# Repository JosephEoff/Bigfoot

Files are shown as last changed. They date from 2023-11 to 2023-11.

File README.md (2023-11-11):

# Bigfoot
Bigfoot is a sewing machine motor speed control made to truly control the speed rather than merely regulating the power.

|Bigfoot and an Adler class 8 sewing machine|
|------------------------------------------|
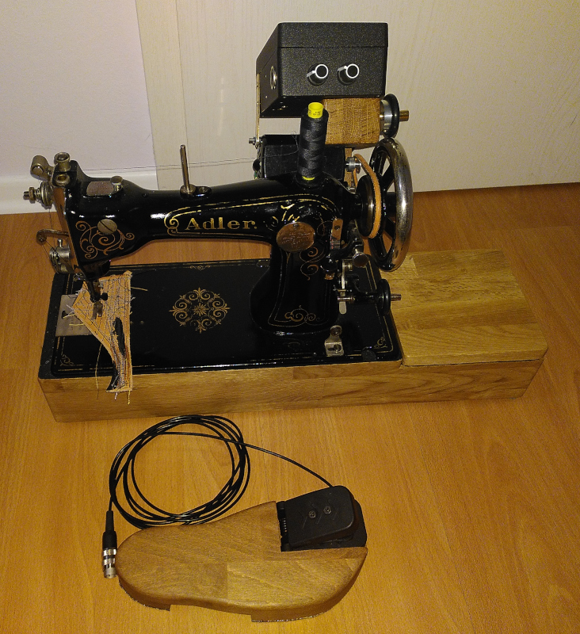
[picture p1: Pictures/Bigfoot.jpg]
Bigfoot and an Adler class 8 sewing machine
||

It uses feedback through a tachometer and a PID controller to maintain the speed set by the foot pedal.  A sewing machine with a Bigfoot controller can steadily work its way through thick stacked leather - provided you are using a solid old vintage sewing machine.

[More details of the background and development of Bigfoot can be found in this series of posts on my blog.](https://josepheoff.github.io/posts/motorcontrol-toc)

Here's Bigfoot and the Adler working through eight, then two, then four layers of fake leather while maintaining a steady speed:

https://github.com/JosephEoff/Bigfoot/assets/13119635/e1ab42f6-7f08-4af5-ab49-b018099e2578

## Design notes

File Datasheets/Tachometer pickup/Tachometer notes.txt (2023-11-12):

I used these photointerrupter modules for the tachometer:
https://www.amazon.de/gp/product/B0817H9436/ref=ppx_yo_dt_b_asin_title_o03_s00?ie=UTF8&psc=1

They included a slotted disc with 20 slots.

The modules have to be modified.  See the images "circuit1.png" and "module1.png" in this folder.

Remove the part marked C1, then replace the part marked R1 with a 750 ohm resistor.

Those two changes will make the output reliable up to 20000 RPM and symmetrical at all speeds.

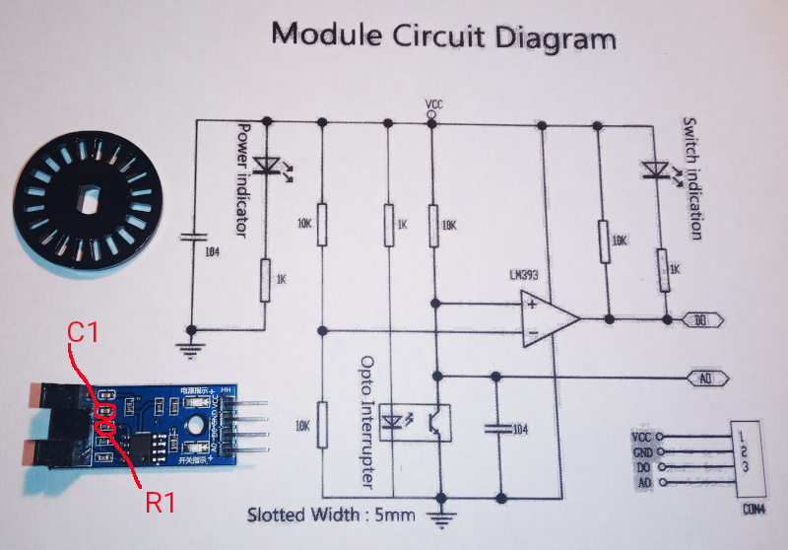
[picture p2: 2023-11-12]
Datasheets/Tachometer pickup/module1.jpg

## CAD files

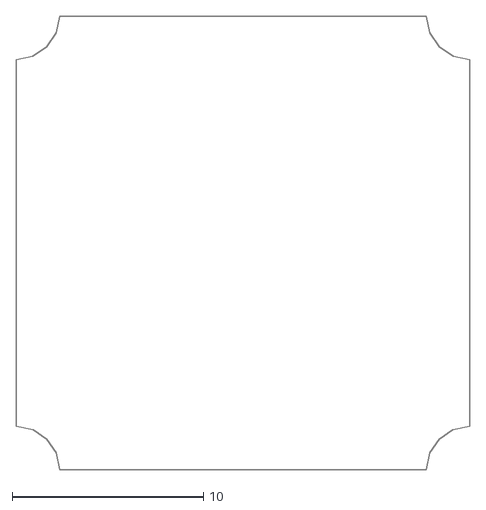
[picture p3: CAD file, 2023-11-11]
KiCad-Files/PCB-outline.dxf
23.7 x 23.7

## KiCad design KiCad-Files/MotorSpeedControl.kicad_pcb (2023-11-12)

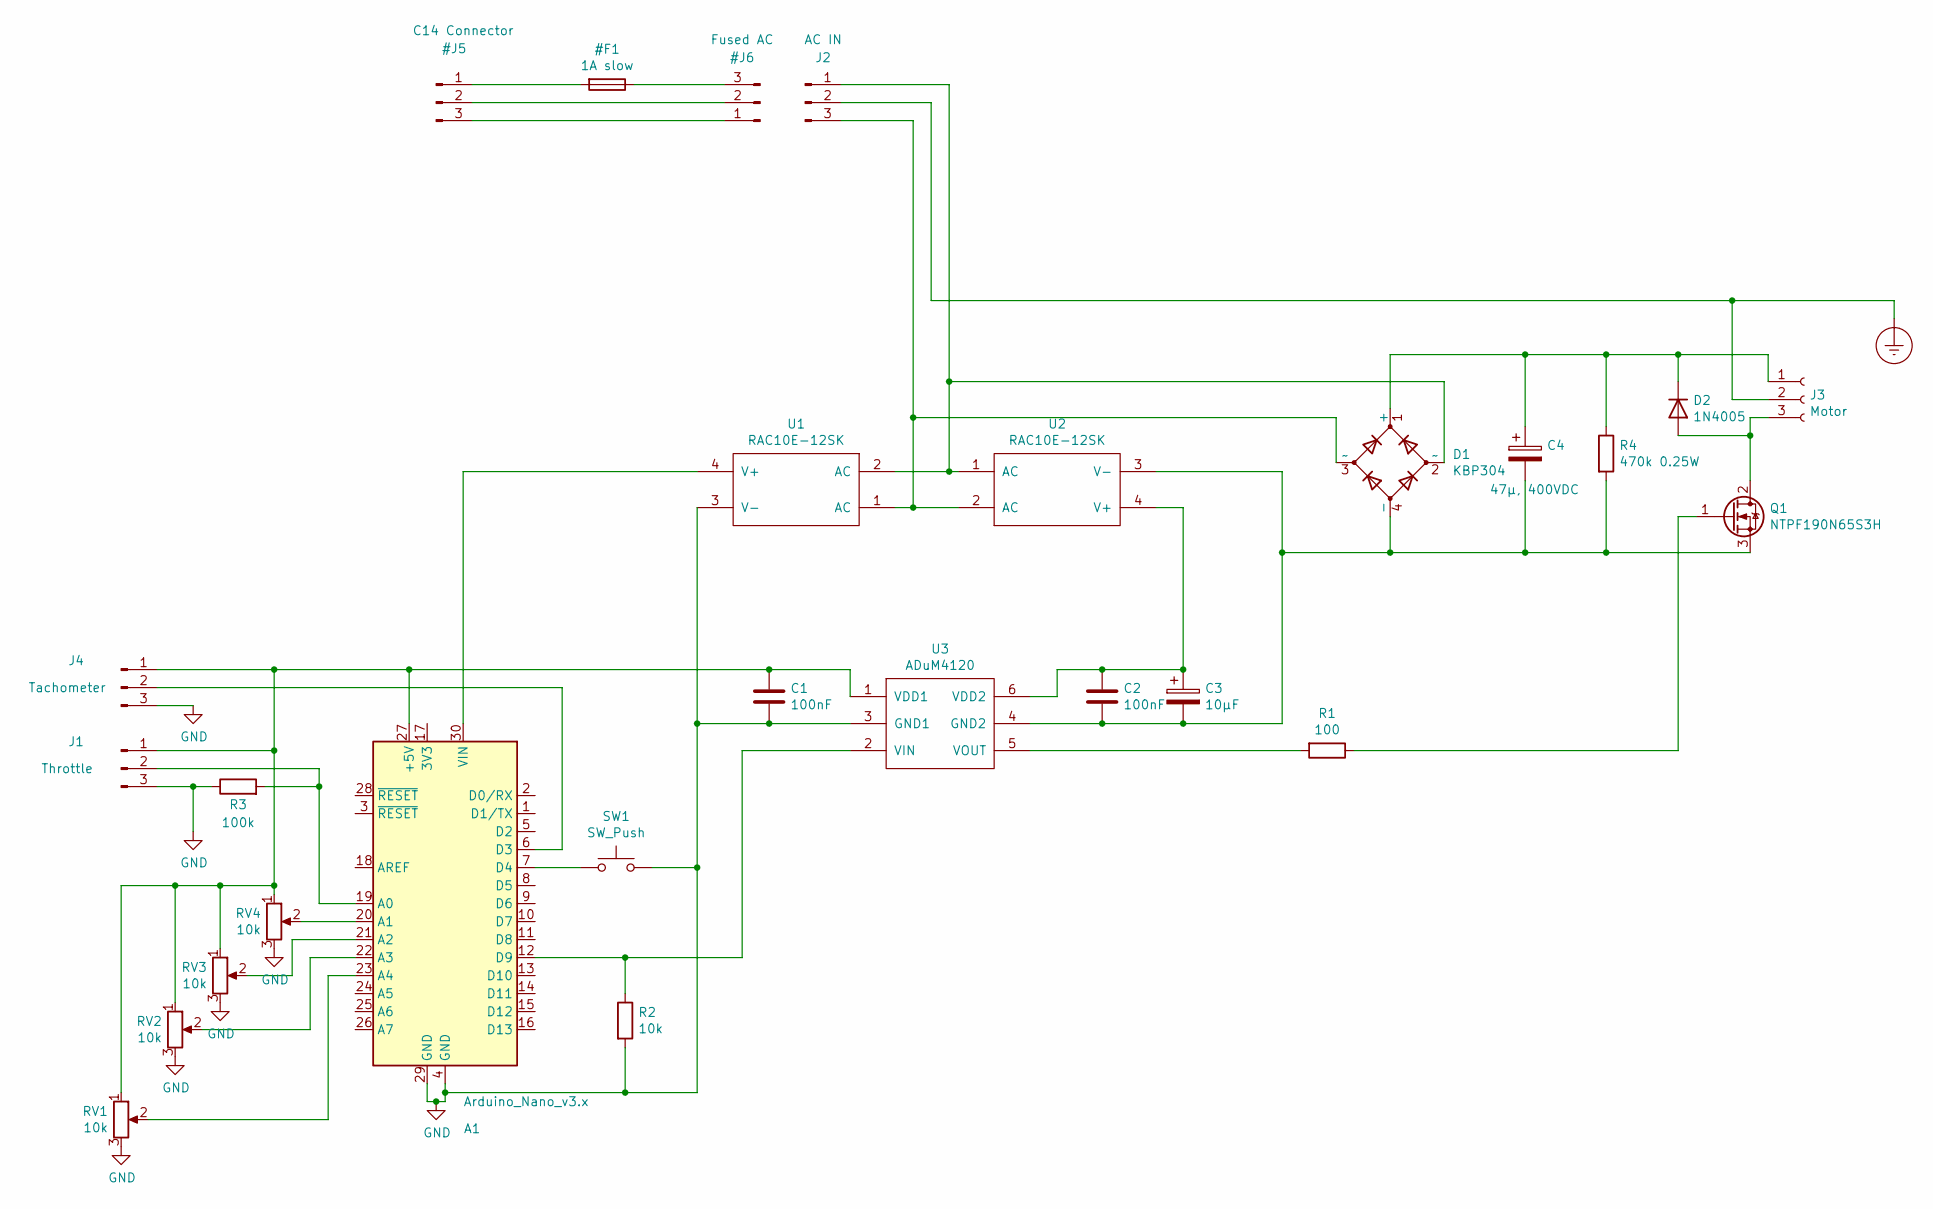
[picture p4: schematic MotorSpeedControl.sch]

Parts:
A1: Arduino_Nano_v3.x; Arduino_Nano
C1, C2: 100nF; C_0805
C3: 10µF; CP_Radial_D5.0mm_P2.50mm
C4: 47µ, 400VDC; CP_Radial_D18.0mm_P7.50mm
D1: KBP304; KBP
D2: 1N4005; D_DO-41_SOD81_P12.70mm_Horizontal
J1: Throttle; Pin_Header_Straight_1x03_Pitch2.54mm
J2: AC IN; TerminalBlock_bornier-3_P5.08mm
J3: Motor; TerminalBlock_bornier-3_P5.08mm
J4: Tachometer; Pin_Header_Straight_1x03_Pitch2.54mm
Q1: NTPF190N65S3H; TO-220-3_Vertical
R1: 100; R_1206
R2: 10k; R_0805
R3: 100k; R_0805
R4: 470k 0.25W; R_Axial_DIN0207_L6.3mm_D2.5mm_P7.62mm_Horizontal
RV1, RV2, RV3, RV4: 10k; Potentiometer_Trimmer_Bourns_3339W_Vertical
SW1: SW_Push; SW_TH_Tactile_Omron_B3F-10xx
U1, U2: RAC10E-12SK; RAC10E
U3: ADuM4120; SOIC-IC6

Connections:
Earth_Protective: J2.2, J3.2
GND: A1.4 (GND), A1.29 (GND), C1.2, J1.3, J4.3, R2.2, R3.1, RV1.3, RV2.3, RV3.3, RV4.3, SW1.2, U1.3 (V-), U3.3 (GND1)
unnamed: A1.6 (D3), J4.2
unnamed: A1.7 (D4), SW1.1
unnamed: A1.12 (D9), R2.1, U3.2 (VIN)
unnamed: A1.19 (A0), J1.2, R3.2
unnamed: A1.20 (A1), RV4.2
unnamed: A1.21 (A2), RV3.2
unnamed: A1.22 (A3), RV2.2
unnamed: A1.23 (A4), RV1.2
unnamed: A1.27 (+5V), C1.1, J1.1, J4.1, RV1.1, RV2.1, RV3.1, RV4.1, U3.1 (VDD1)
unnamed: A1.30 (VIN), U1.4 (V+)
unnamed: C2.1, C3.1, U2.4 (V+), U3.6 (VDD2)
unnamed: C2.2, C3.2, C4.2, D1.4 (-), Q1.3 (S), R4.2, U2.3 (V-), U3.4 (GND2)
unnamed: C4.1, D1.1 (+), D2.1 (K), J3.1, R4.1
unnamed: D1.2 (~~), J2.1, U1.2 (AC), U2.1 (AC)
unnamed: D1.3 (~~), J2.3, U1.1 (AC), U2.2 (AC)
unnamed: D2.2 (A), J3.3, Q1.2 (D)
unnamed: Q1.1 (G), R1.1
unnamed: R1.2, U3.5 (VOUT)

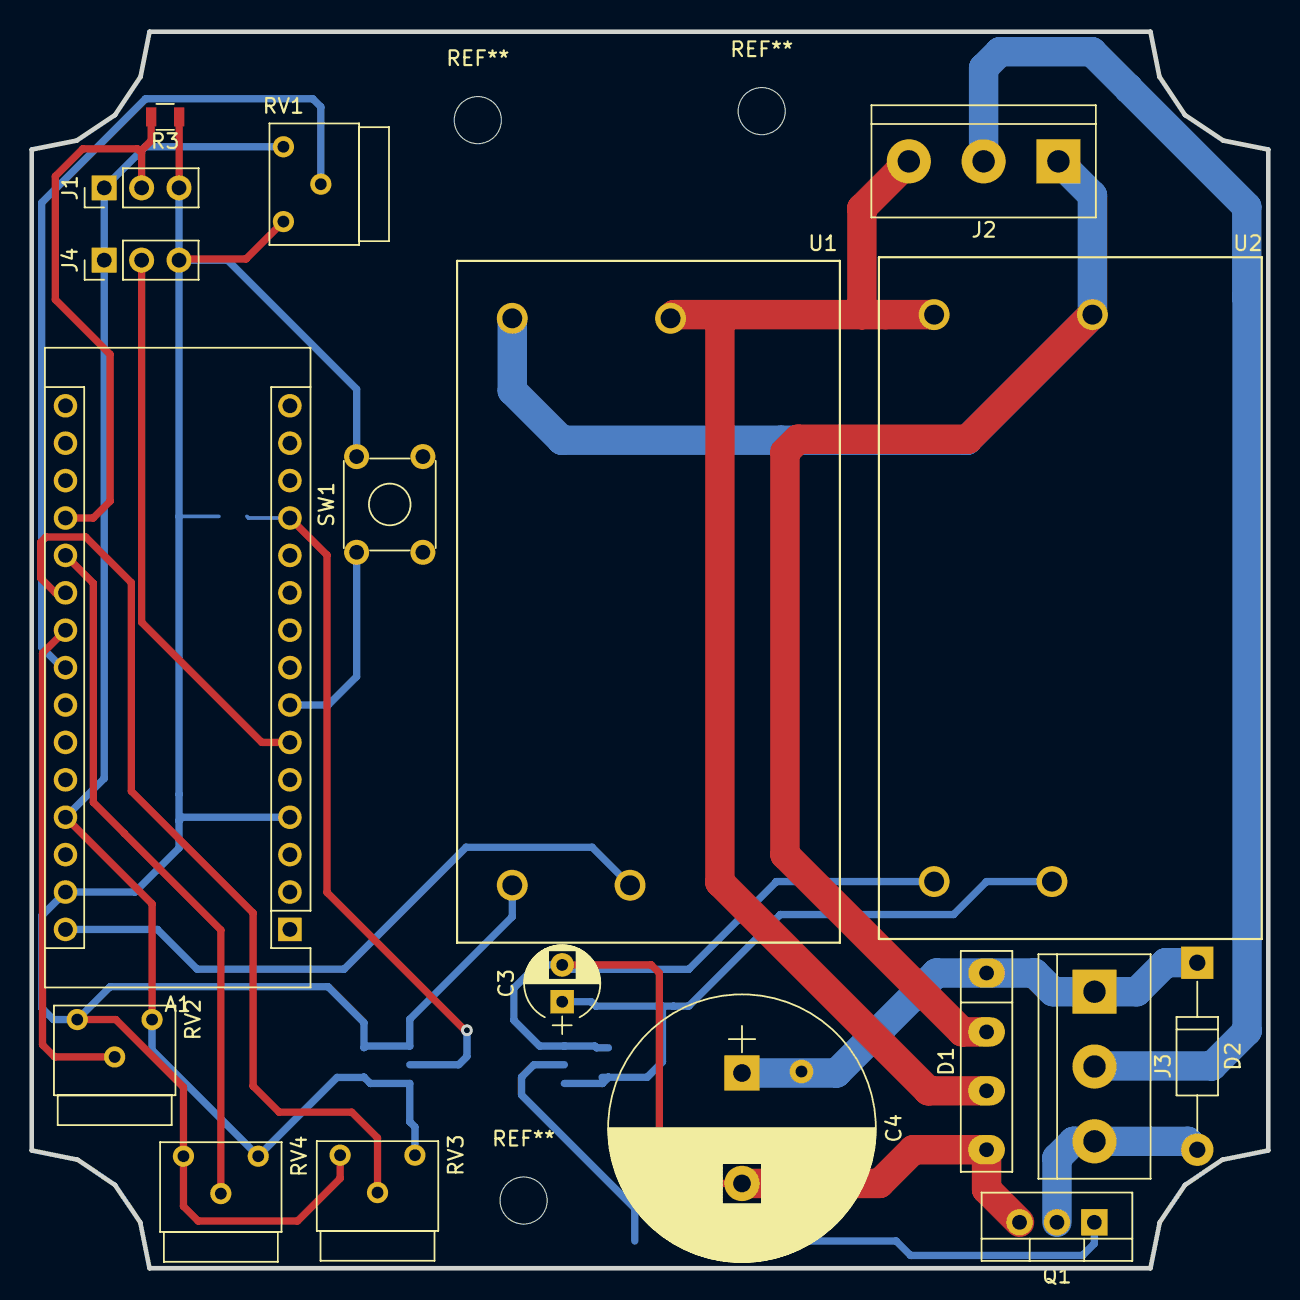
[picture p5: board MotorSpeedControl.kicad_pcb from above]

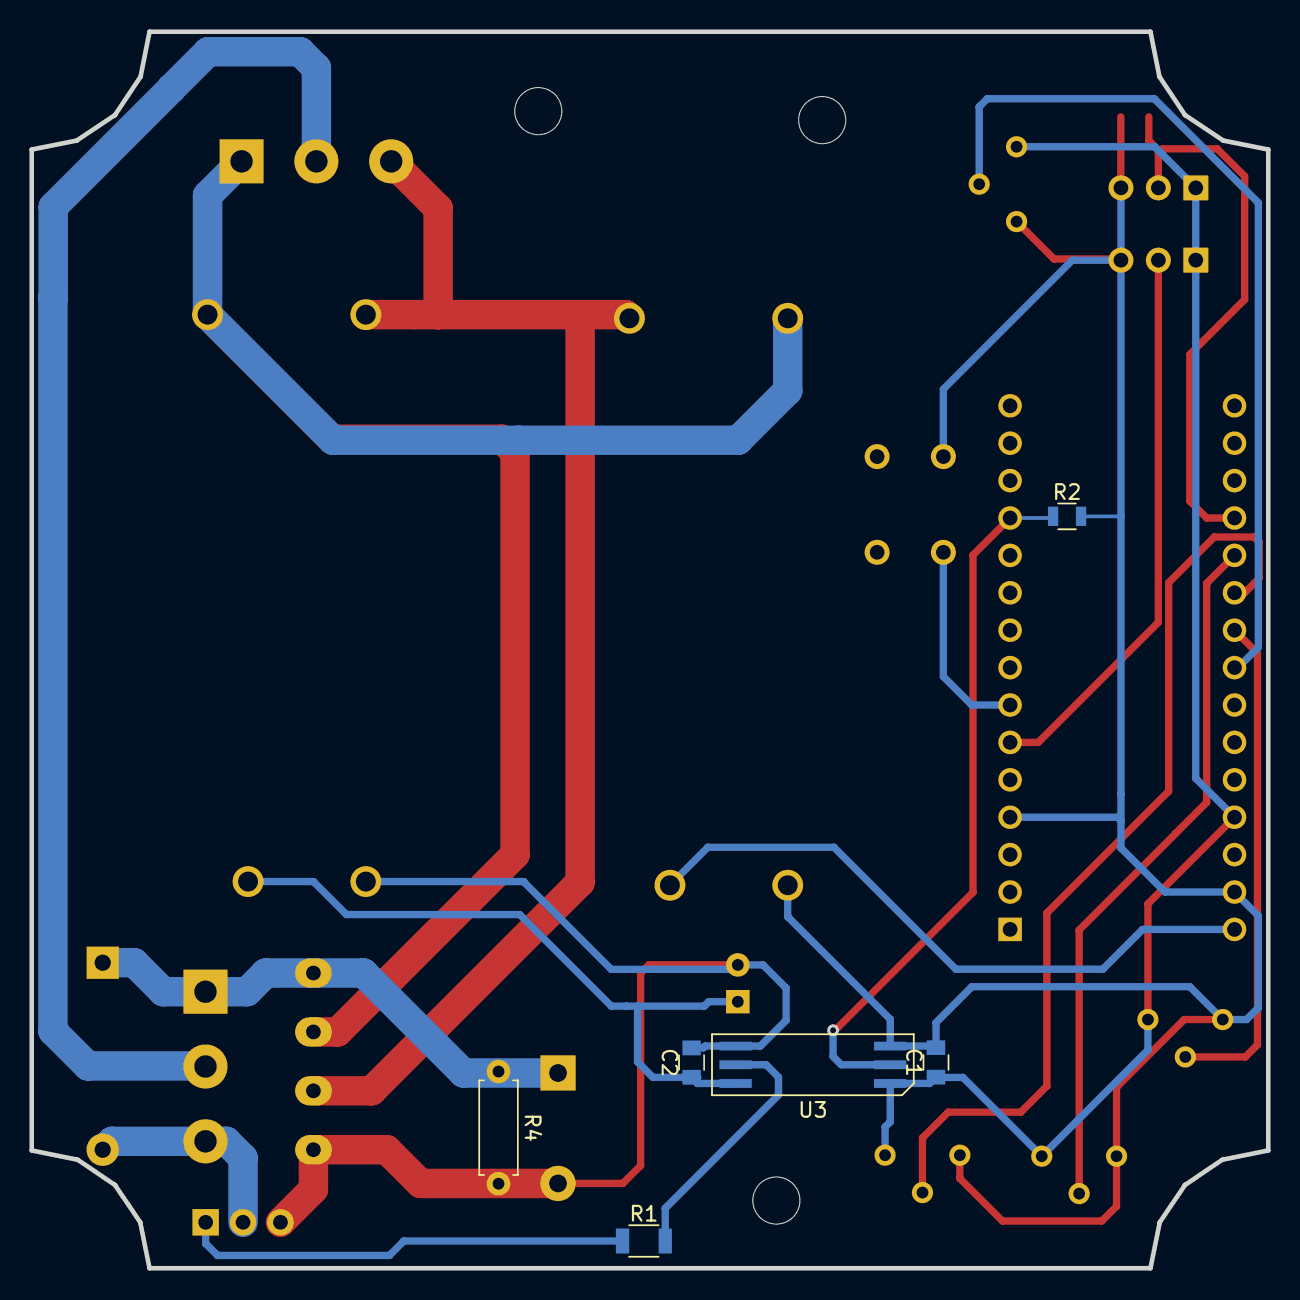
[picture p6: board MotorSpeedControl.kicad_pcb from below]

Board: 2 copper layers, 84.0 x 84.0 mm, 24 parts (6 on the bottom side), 20 nets.

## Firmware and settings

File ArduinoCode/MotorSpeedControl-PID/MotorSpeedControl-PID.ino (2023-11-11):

#include <EEPROM.h>
#include <TimerOne.h>
#include <AutoPID.h>
#include <pidautotuner.h>
//https://github.com/jackw01/arduino-pid-autotuner


#define PEDAL A0
#define KICKOVERPOINT A1
#define PEDAL_MINIMUM A2
#define FIXEDSPEED A3
#define MAXSPEED A4

#define PWM_PIN 9
#define PULSE_PIN 3
#define BUTTON_PIN 4
#define period 50 // 50 microseconds = 20kHz


int pedalValue = 0;
float pedalAverage = 0.0;
int pedalMinimum = 1023;
int kickover = 1023;
int fixedspeed = 0;
int maxspeed = 0;
int pwmValue = 0;
double StitchesPerMinute = 0;
double TargetSPM = 0;
double FixedSPM = 0;
double MaxSPM = 0;
bool stopped = true;
bool startmotor = false;

volatile byte pulseCounter = 0;
volatile unsigned long pulseTime[2];
volatile bool gotPulse = false;

bool stillSpinning = true;

// Sewing machine parameters:
#define STUCKMOTORTIMEOUT_SECONDS 5
#define SPMERROR 5000 //Outrageous number of stitches per minute calculated.
#define HANDWHEEL_DIAMETER 135
#define TACHOWHEEL_DIAMETER 40
// Use the same unit for both measurements.  I used millimeters.
#define PULSESPERROTATION  20  //Number of slots in the tachometer slotted wheel.
#define SLOWESTSPEED 45 //lowest speed possible in stitches per minute.  Applies to the fixed speed knob as well as the variable range.
#define FIXEDSPEED_MAX 200 //maximum stitches per minute for the fixed speed knob
#define FASTESTSPEED 1000 //Stitches per minute.  Absolute maximum speed allowed.
#define PEDALHYSTERESIS 30 //ADC counts difference between the stop position and the sto position of the pedal.
#define DKP 4.94  //Replace with struct and flash storage after autotune
#define DKI 0.38 //Replace with struct and flash storage after autotune
#define DKD 62.75 //Replace with struct and flash storage after autotune
#define OUTPUT_MIN 10 //at 20KHz PWM, the Arduino PWM doesn't work below about 10 - the output just stays low.
#define OUTPUT_MAX 1023
#define PIDLoop_milliseconds 5
const float stitchToRPMRatio = (float)TACHOWHEEL_DIAMETER / (float)HANDWHEEL_DIAMETER;
const float pulseToRPMRatio = 1.0 / (float)PULSESPERROTATION;
unsigned long microsecondsStuckMotorTimeout = STUCKMOTORTIMEOUT_SECONDS * 1000000;
unsigned long microsocondsOfLastPulse = 0;

const String Signature = "Adelheid";

const int EEPROM_Address = 0;

double PWMValue = 0;

AutoPID MotorPID(&StitchesPerMinute, &TargetSPM, &PWMValue, OUTPUT_MIN, OUTPUT_MAX, DKP, DKI, DKD);

int buttonPressCounter = 0;

struct PID_Parameters{
  double KP;
  double KI;
  double KD;
  String Signature;
};

PID_Parameters Parameters = {0,0,0,""};

void setup() {
  Serial.begin(115200);
  pinMode(PWM_PIN, OUTPUT);
  Timer1.initialize(period);
  Timer1.pwm(PWM_PIN, 0);
  pinMode(PULSE_PIN, INPUT_PULLUP);
  pinMode(BUTTON_PIN, INPUT_PULLUP);
  attachInterrupt(digitalPinToInterrupt(PULSE_PIN), tachometer_ISR, RISING);
  MotorPID.setTimeStep(PIDLoop_milliseconds);
  //MotorPID.setBangBang(50);
  pinMode(LED_BUILTIN, OUTPUT);
  LoadPIDParametersFromEEPROM();
}

void  tachometer_ISR() {
  if (gotPulse) {
    return;
  }
  pulseTime[pulseCounter] = micros();
  if (pulseCounter == 1) {
    gotPulse = true;
    pulseCounter = 0;
  }
  else {
    pulseCounter += 1;
  }
}

void loop() {
  if (digitalRead(BUTTON_PIN) == LOW) {
    buttonPressCounter += 1;
    digitalWrite(LED_BUILTIN, HIGH);
  }
  else{
     buttonPressCounter = 0;
    digitalWrite(LED_BUILTIN, LOW);
  }
  
  if (buttonPressCounter > 10) {
    buttonPressCounter = 0;
    DoAutoTune();
  }
  pedalMinimum = analogRead(PEDAL_MINIMUM);
  pedalValue = analogRead(PEDAL);
  kickover = analogRead(KICKOVERPOINT);
  maxspeed = analogRead(MAXSPEED);
  fixedspeed = analogRead(FIXEDSPEED);
  FixedSPM = mapf((float)fixedspeed, 0.0, 1023.0, (float)SLOWESTSPEED, (float)FIXEDSPEED_MAX);
  MaxSPM = mapf((float)maxspeed, 0.0, 1023.0, (float)SLOWESTSPEED, (float)FASTESTSPEED);
  pedalAverage = pedalAverage + (((float)pedalValue - pedalAverage)*0.02);
  
  if ((int)pedalAverage <= (pedalMinimum)) {
    //Stop.  Pedal is not pressed.
    MotorPID.stop();
    MotorPID.reset();
    pwmValue = 0;
    TargetSPM = 0;
    Timer1.pwm(PWM_PIN, pwmValue);
    stopped = true;
    startmotor = false;
    return;
  }
  if ((int)pedalAverage >=  pedalMinimum + PEDALHYSTERESIS){
    startmotor = true;
  }
  if (!startmotor){
    return;
  }
  if ((int)pedalAverage <= kickover) {
    TargetSPM = FixedSPM;
  }
  else {
    TargetSPM = mapf(pedalAverage, (float)kickover, 1023.0, FixedSPM, MaxSPM);
  }
  if (stopped) {
    stopped = false;
    //slap the motor and make it turn.
    SlapMotor();
    microsocondsOfLastPulse = micros();
  }
  UpdateSPM();

  if (stillSpinning) {
    MotorPID.run();
    Timer1.pwm(PWM_PIN, (int)PWMValue);
  }
  else {
    //Motor stuck, shutoff.
    Timer1.pwm(PWM_PIN, 0);
  }
}

void UpdateSPM() {
  if (gotPulse) {
    CalculateStitchesPerMinute();
    gotPulse = false;
    stillSpinning = true;
    microsocondsOfLastPulse = micros();
  }

  //Stuck motor detection
  if (micros() - microsocondsOfLastPulse >= microsecondsStuckMotorTimeout) {
    stillSpinning = false;
  }
}

void SlapMotor(){
    Timer1.pwm(PWM_PIN, 1023);
    delay(15);
}

void CalculateStitchesPerMinute() {
  // Convert pulse time to pulses per second = 1 second / (pulse time * pulses per rotatation)
  // Convert pulses per second to RPM = pulses per second * 60
  // Convert RPM to stitches per minute = RPM * ratio
  float pulsespersecond = (float)(1000000.0 / (pulseTime[1] - pulseTime[0]));
  float pulsesperminute = pulsespersecond * 60.0;
  float RPM = pulsesperminute * pulseToRPMRatio;
  float SPM = RPM * stitchToRPMRatio;
  if (SPM >= SPMERROR) {
    //Outrageous number of stitches per minute calculated.
    //This happens when a slot on the tachometer wobbles back and forth in front of the LED.
    //It happens mostly at very low speed.
    //Ignore outrageous numbers.
    //Slap the motor to get past the edge condition.
    SlapMotor();
    return;
  }
  StitchesPerMinute = SPM;
}

void DoAutoTune() {
  PIDAutotuner tuner = PIDAutotuner();
  long loopInterval = 1000 * PIDLoop_milliseconds;
  tuner.setTargetInputValue(200); //Target 200 stitches per minute
  tuner.setLoopInterval(loopInterval);
  tuner.setOutputRange(0, 1023);
  //PIDAutotuner::ZNModeBasicPID, PIDAutotuner::ZNModeLessOvershoot, PIDAutotuner::ZNModeNoOvershoot
  tuner.setZNMode(PIDAutotuner::ZNModeLessOvershoot);
  tuner.startTuningLoop(micros());

  // Run a loop until tuner.isFinished() returns true
  long microseconds;
  while (!tuner.isFinished()) {

    long prevMicroseconds = microseconds;
    microseconds = micros();
    UpdateSPM();
    double output = tuner.tunePID(StitchesPerMinute, microseconds);
    Timer1.pwm(PWM_PIN, (int)output);
    while (micros() - microseconds < loopInterval) delayMicroseconds(1);
  }
  Timer1.pwm(PWM_PIN,0);

  // Get PID gains - set your PID controller's gains to these
  Parameters.KP = tuner.getKp();
  Parameters.KI = tuner.getKi();
  Parameters.KD = tuner.getKd();
  SavePIDParametersToEEPROM();
  Serial.print("KP: ");
  Serial.println(Parameters.KP);
  Serial.print("KI: ");
  Serial.println(Parameters.KI);
  Serial.print("KD: ");
  Serial.println(Parameters.KD);
 
}

void LoadPIDParametersFromEEPROM(){
  EEPROM.get(EEPROM_Address, Parameters);
  if (Parameters.Signature != Signature){
    //Set default values and save to EEPROM
    Parameters.KP = DKP;
    Parameters.KI = DKI;
    Parameters.KD = DKD;
    SavePIDParametersToEEPROM();
  }
  MotorPID.setGains(Parameters.KP, Parameters.KI, Parameters.KP);
}

void SavePIDParametersToEEPROM(){
  Parameters.Signature = Signature;
  EEPROM.put(EEPROM_Address, Parameters);
  Serial.println("Saved PID parameters.");
}

float mapf(float x, float in_min, float in_max, float out_min, float out_max)
{
  return (x - in_min) * (out_max - out_min) / (in_max - in_min) + out_min;
}

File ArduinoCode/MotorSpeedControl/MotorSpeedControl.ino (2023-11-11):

#include <TimerOne.h>

#define PEDAL A0
#define KICKOVERPOINT A1
#define PEDAL_MINIMUM A2
#define SLOWSPEED A3
#define MAXSPEED A4

#define PWM_PIN 9
#define PULSE_PIN 3
#define period 50 // 50 microseconds = 20kHz
int pedalValue=0;
int pedalMinimum =1023;
int kickover = 1023;
int slowspeed = 0;
int maxspeed = 0;
int pwmValue = 0;


void setup() {
  Serial.begin(1000000);
  pinMode(PWM_PIN, OUTPUT);
  Timer1.initialize(period);
  Timer1.pwm(PWM_PIN,0);
  pinMode (PULSE_PIN, INPUT);
  
}

void loop() {

  pedalMinimum = analogRead(PEDAL_MINIMUM);  
  pedalValue = analogRead(PEDAL);
  kickover = analogRead(KICKOVERPOINT);
  slowspeed = analogRead(SLOWSPEED);
  maxspeed = analogRead(MAXSPEED);
   
 
  if (pedalValue<=pedalMinimum){
    //Stop.  Pedal is not pressed.
    pwmValue = 0;
  }
  else if (pedalValue<=kickover){
    pwmValue = slowspeed;    
  }
  else {
    pwmValue = map(pedalValue,pedalMinimum, 1023, slowspeed, maxspeed);
  }
  
  Timer1.pwm(PWM_PIN, pwmValue);

  delay(5);
}

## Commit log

2023-11-11 Initial commit. Still a mess.
    [MotorSpeedControl.kicad_pcb, MotorSpeedControl.sch, PCB-outline.dxf]
2023-11-11 A little bit of cleanup.
    [MotorSpeedControl.kicad_pcb, MotorSpeedControl.sch, PCB-outline.dxf]
2023-11-12 Updated schematic.
    [MotorSpeedControl.kicad_pcb, MotorSpeedControl.sch]
